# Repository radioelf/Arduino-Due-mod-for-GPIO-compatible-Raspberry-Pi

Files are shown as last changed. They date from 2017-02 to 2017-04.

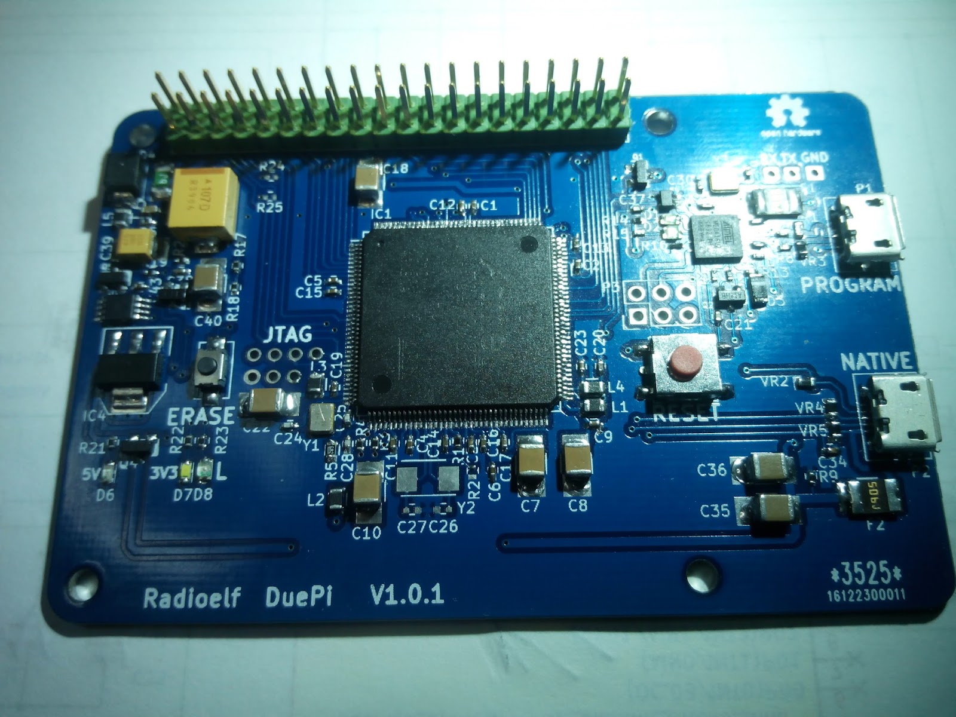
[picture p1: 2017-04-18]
DuePi.jpg

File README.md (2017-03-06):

# Arduino Due mod for GPIO compatible Raspberry Pi
Creative Commons License Disclaimer

UNLESS OTHERWISE MUTUALLY AGREED TO BY THE PARTIES IN WRITING, LICENSOR OFFERS THE WORK AS-IS AND MAKES NO REPRESENTATIONS 
OR WARRANTIES OF ANY KIND CONCERNING THE WORK, EXPRESS, IMPLIED, STATUTORY OR OTHERWISE, INCLUDING, WITHOUT LIMITATION,
WARRANTIES OF TITLE, MERCHANTIBILITY, FITNESS FOR A PARTICULAR PURPOSE, NONINFRINGEMENT, OR THE ABSENCE OF LATENT OR 
OTHER DEFECTS, ACCURACY, OR THE PRESENCE OF ABSENCE OF ERRORS, WHETHER OR NOT DISCOVERABLE. SOME JURISDICTIONS DO NOT 
ALLOW THE EXCLUSION OF IMPLIED WARRANTIES, SO SUCH EXCLUSION MAY NOT APPLY TO YOU. EXCEPT TO THE EXTENT REQUIRED BY 
APPLICABLE LAW, IN NO EVENT WILL LICENSOR BE LIABLE TO YOU ON ANY LEGAL THEORY FOR ANY SPECIAL, INCIDENTAL, CONSEQUENTIAL, 
PUNITIVE OR EXEMPLARY DAMAGES ARISING OUT OF THIS LICENSE OR THE USE OF THE WORK, EVEN IF LICENSOR HAS BEEN ADVISED OF 
THE POSSIBILITY OF SUCH DAMAGES.

http://creativecommons.org/licenses/by-sa/3.0/

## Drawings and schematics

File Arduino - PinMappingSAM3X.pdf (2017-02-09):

# SAM3X-Arduino Pin Mapping

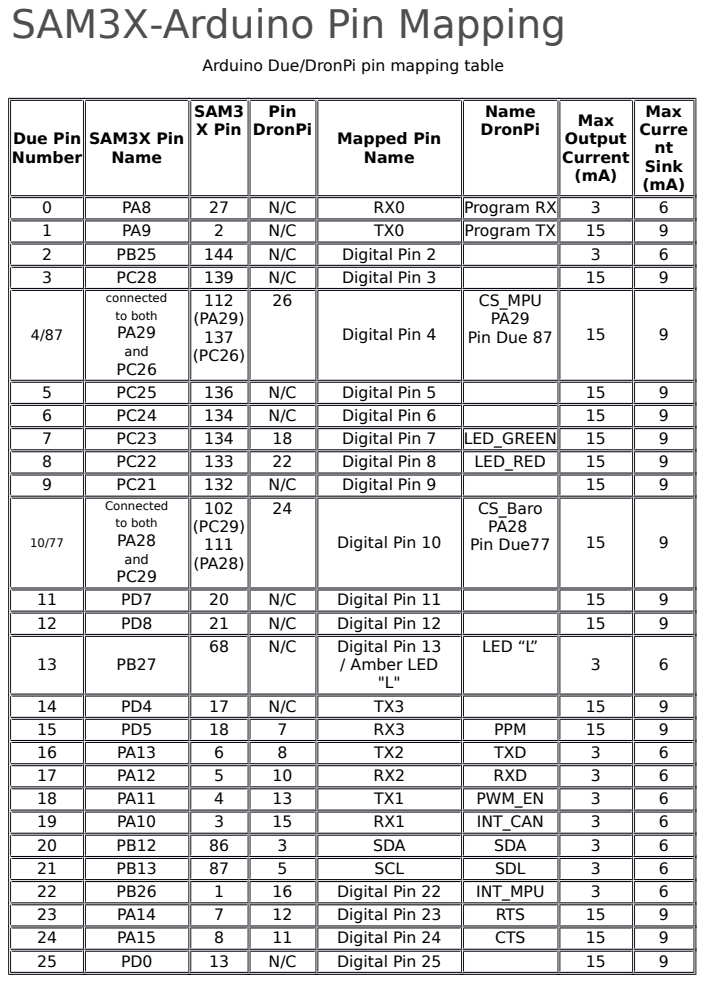
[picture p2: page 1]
Due Pin Number; SAM3X Pin Name; SAM3 X Pin; Pin; DronPi; Mapped Pin; Name; Max; Output Current (mA); Max Curre nt Sink (mA); Program RX; Program TX; Digital Pin 2; Digital Pin 3; connected to both PA29 and PC26; Digital Pin 4; CS_MPU PA29; Pin Due 87; Digital Pin 5; Digital Pin 6; Digital Pin 7; LED_GREEN; Digital Pin 8; LED_RED; Digital Pin 9; Connected to both PA28 and PC29; Digital Pin 10; CS_Baro PA28; Pin Due77; Digital Pin 11; Digital Pin 12; Digital Pin 13; / Amber LED "L"; LED “L”; PPM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

Arduino Due/DronPi pin mapping table

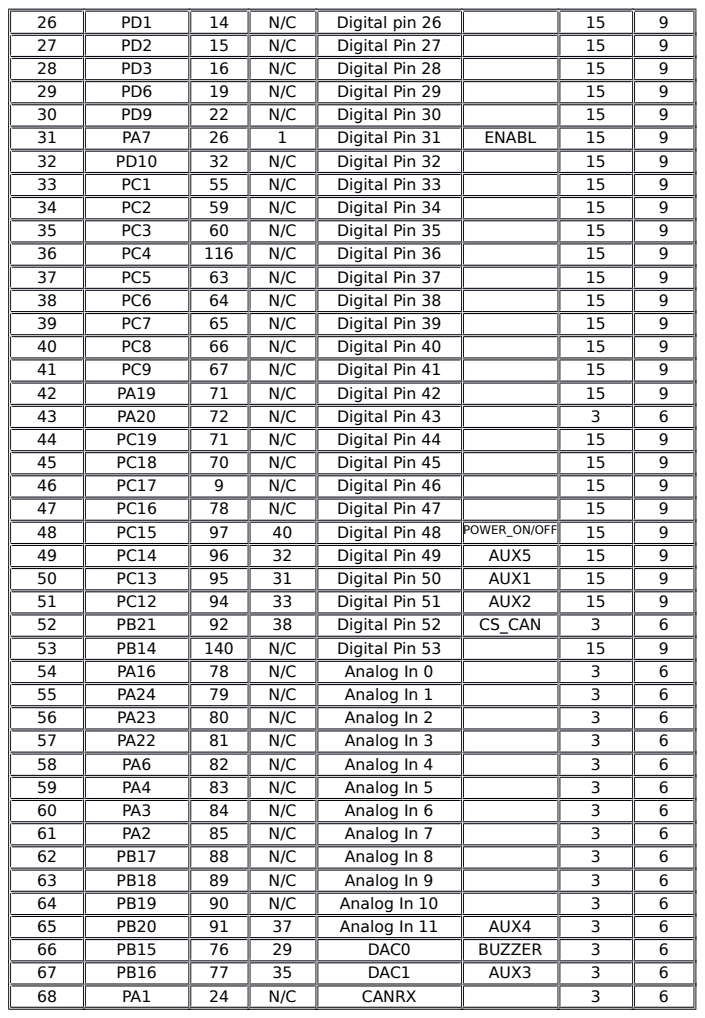
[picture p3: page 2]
Digital pin 26; Digital Pin 27; Digital Pin 28; Digital Pin 29; Digital Pin 30; Digital Pin 31; ENABL; Digital Pin 32; Digital Pin 33; Digital Pin 34; Digital Pin 35; Digital Pin 36; Digital Pin 37; Digital Pin 38; Digital Pin 39; Digital Pin 40; Digital Pin 41; Digital Pin 42; Digital Pin 43; Digital Pin 44; Digital Pin 45; Digital Pin 46; Digital Pin 47; Digital Pin 48 POWER_ON/OFF; Digital Pin 49; AUX5; Digital Pin 50; AUX1; Digital Pin 51; AUX2; Digital Pin 52; CS_CAN; Digital Pin 53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

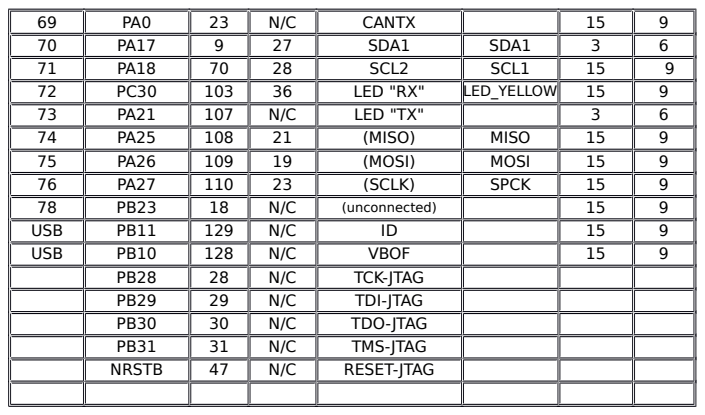
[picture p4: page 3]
CANTX; SDA1; SCL2; SCL1; LED "RX"; LED_YELLOW; LED "TX"; (MISO); MISO; (MOSI); MOSI; (SCLK); SPCK; (unconnected); USB; VBOF; TCK-JTAG; TDI-JTAG; TDO-JTAG; TMS-JTAG; NRSTB; RESET-JTAG

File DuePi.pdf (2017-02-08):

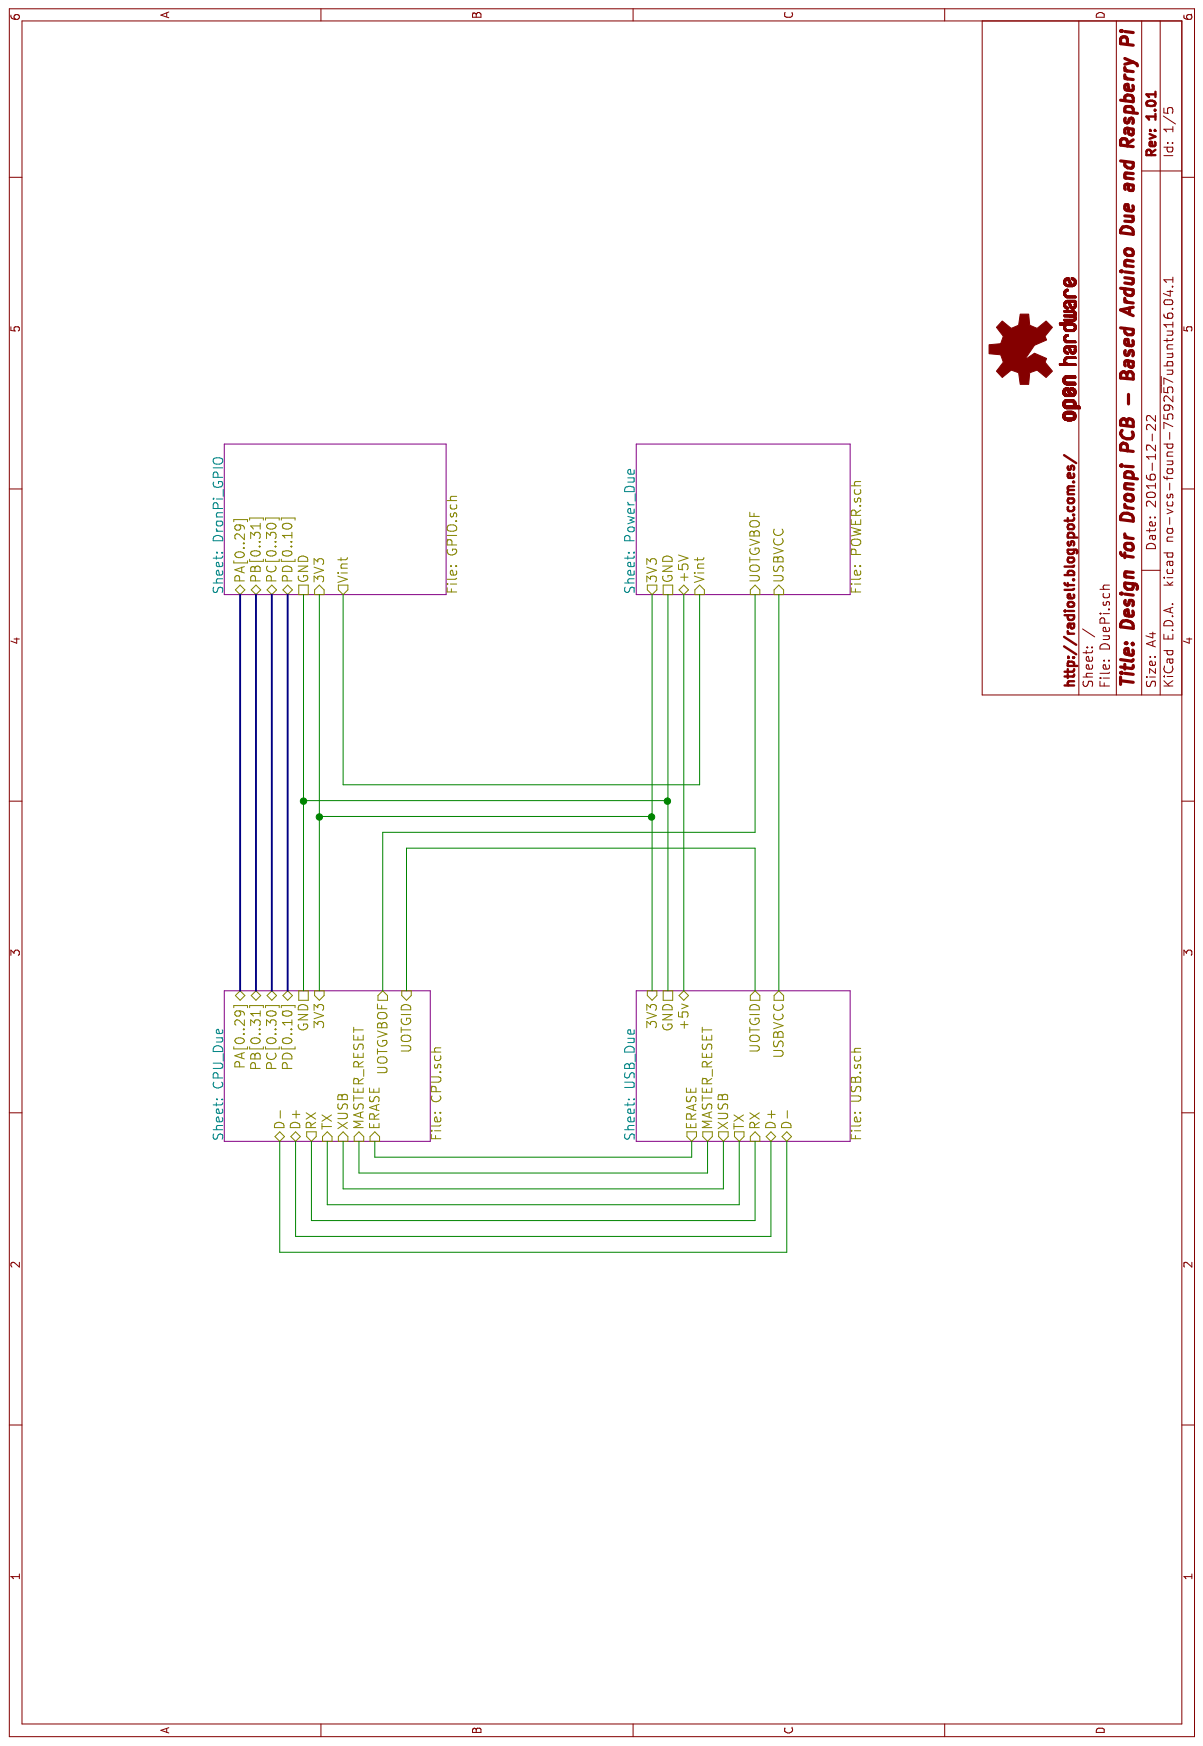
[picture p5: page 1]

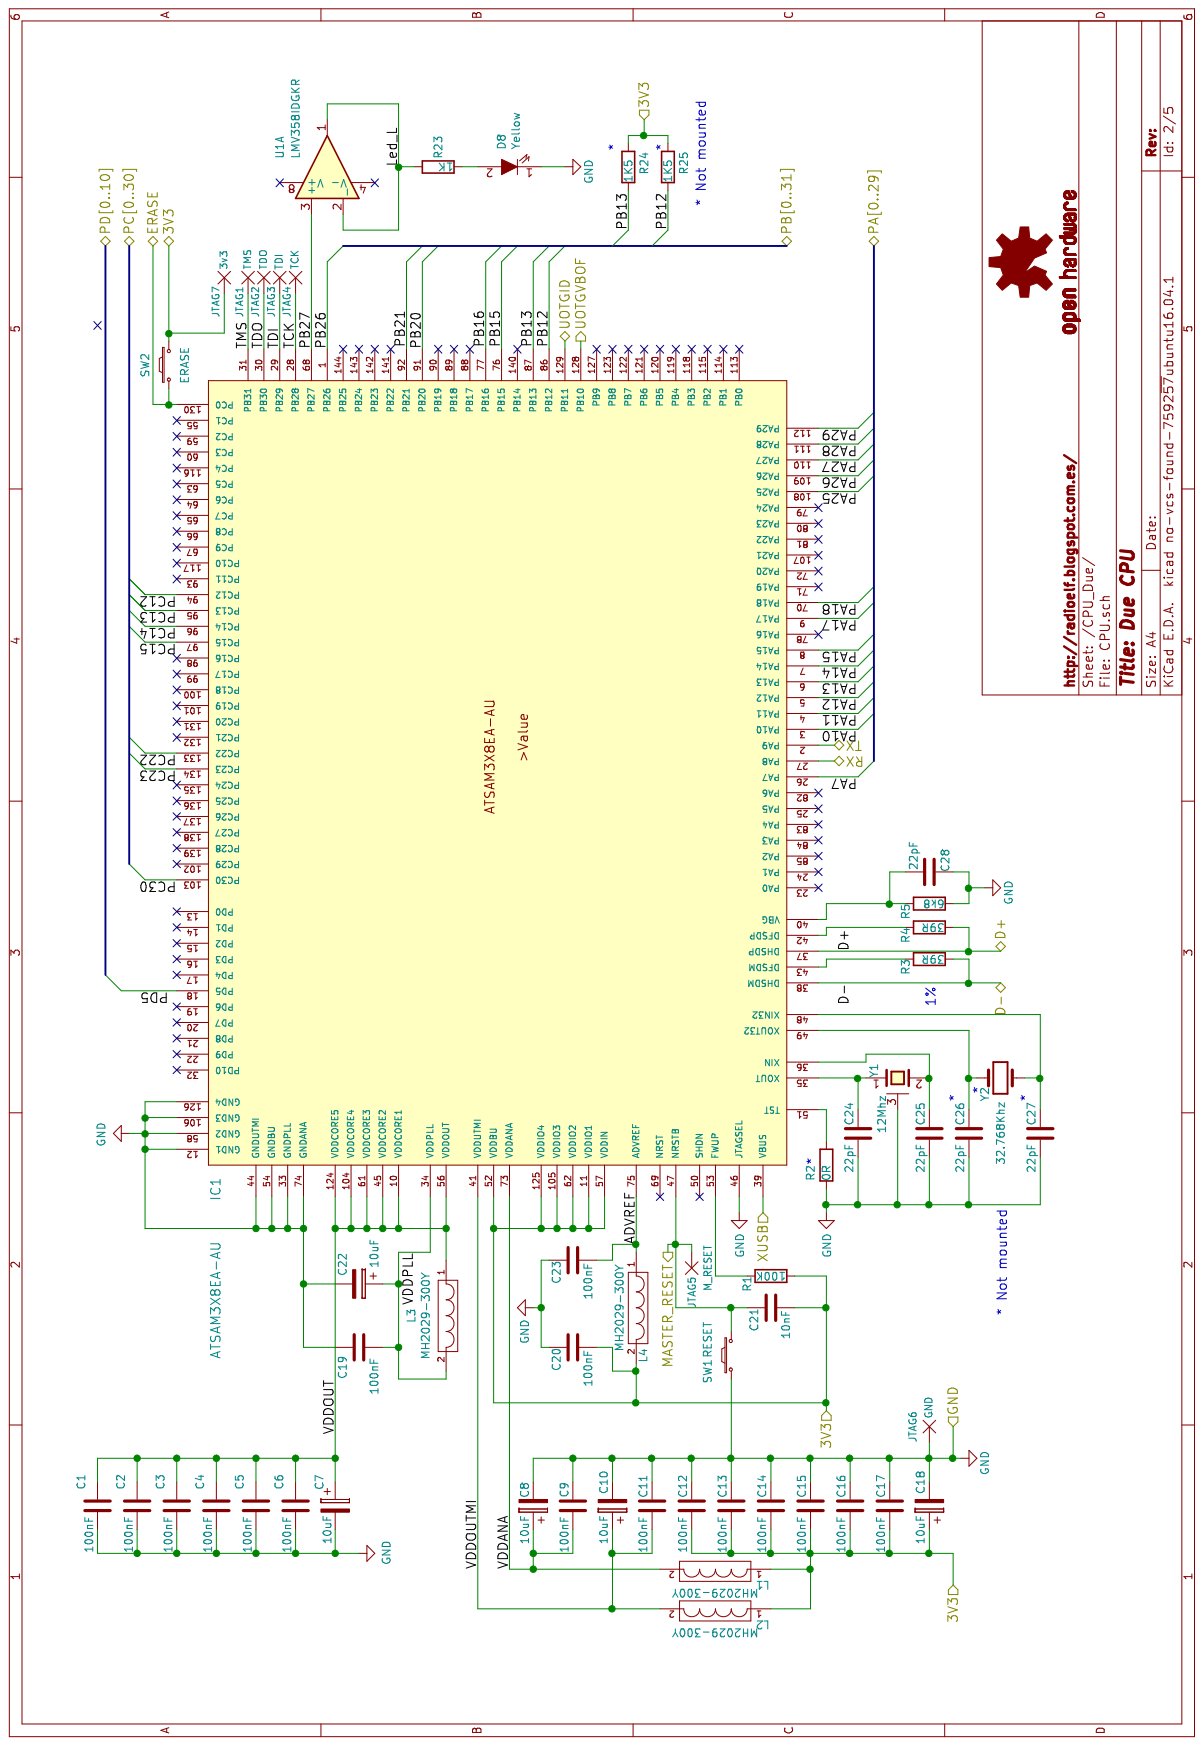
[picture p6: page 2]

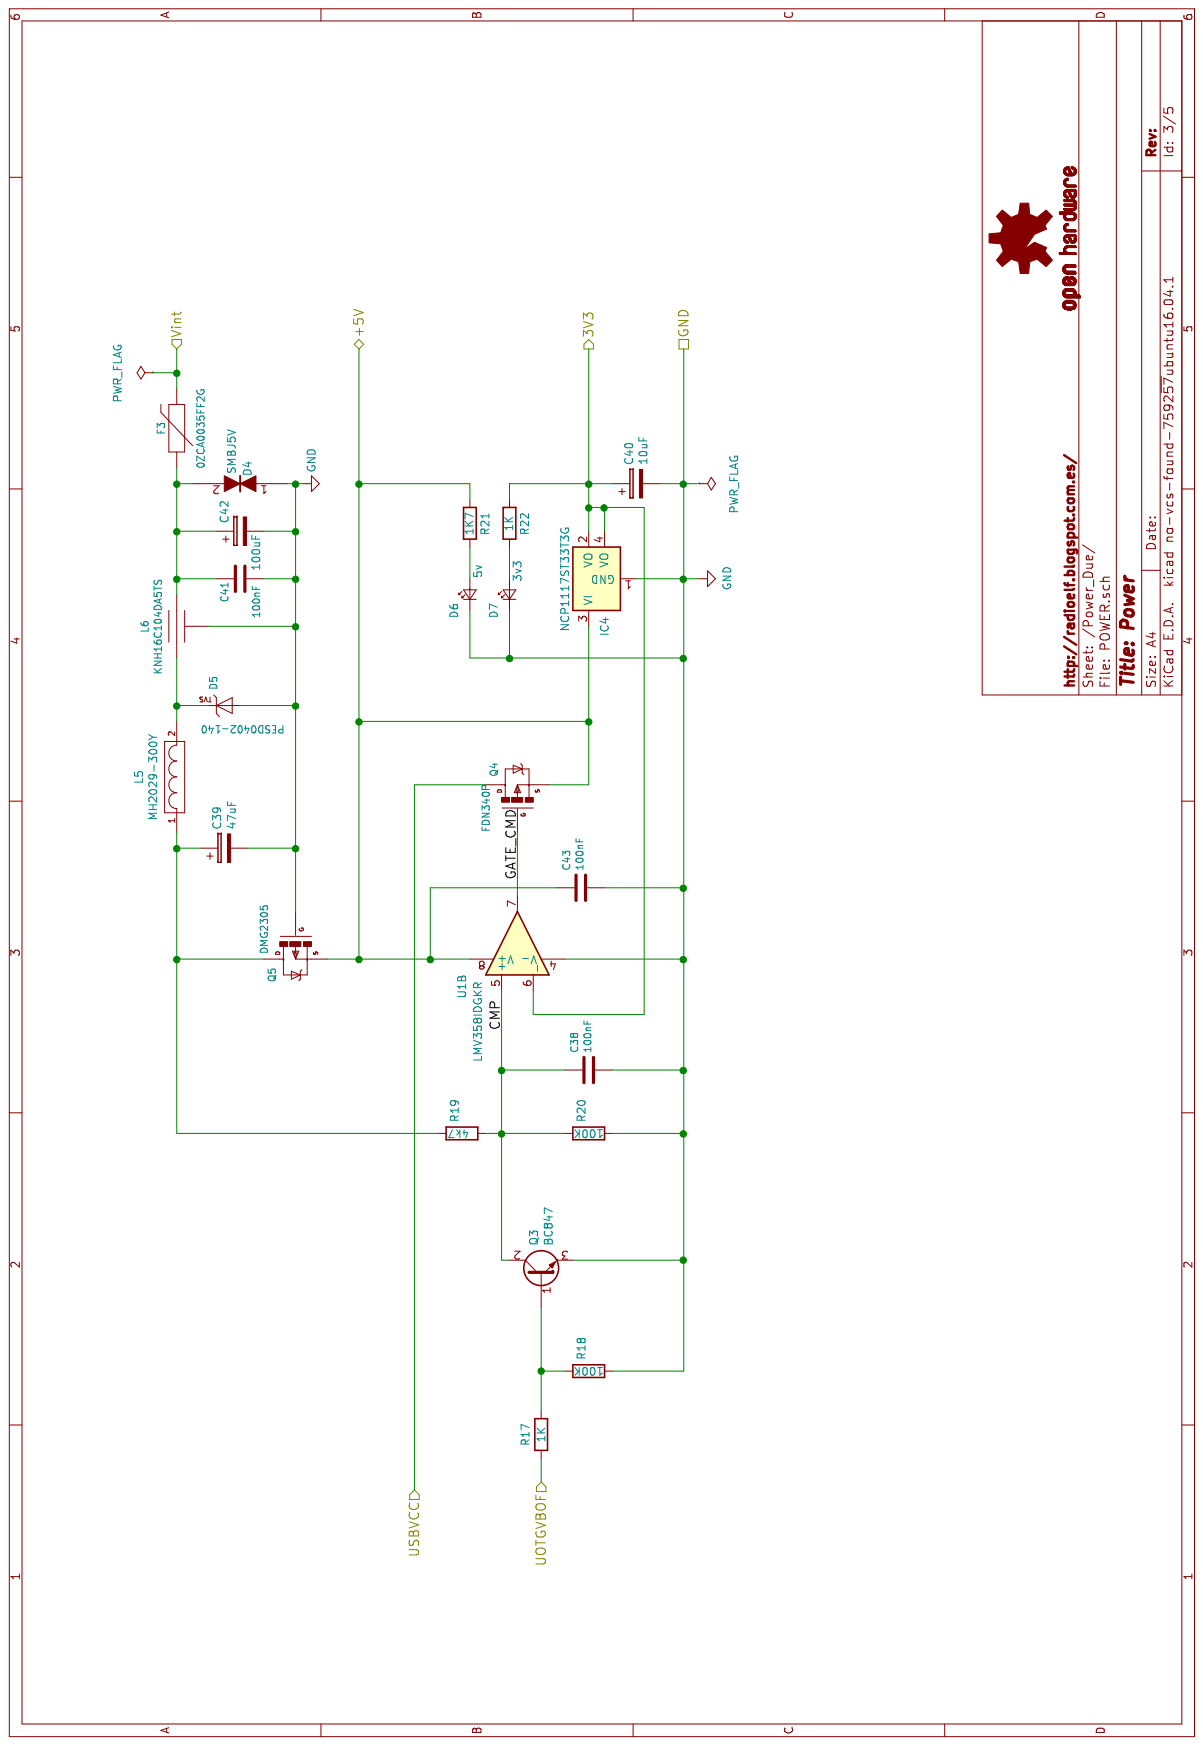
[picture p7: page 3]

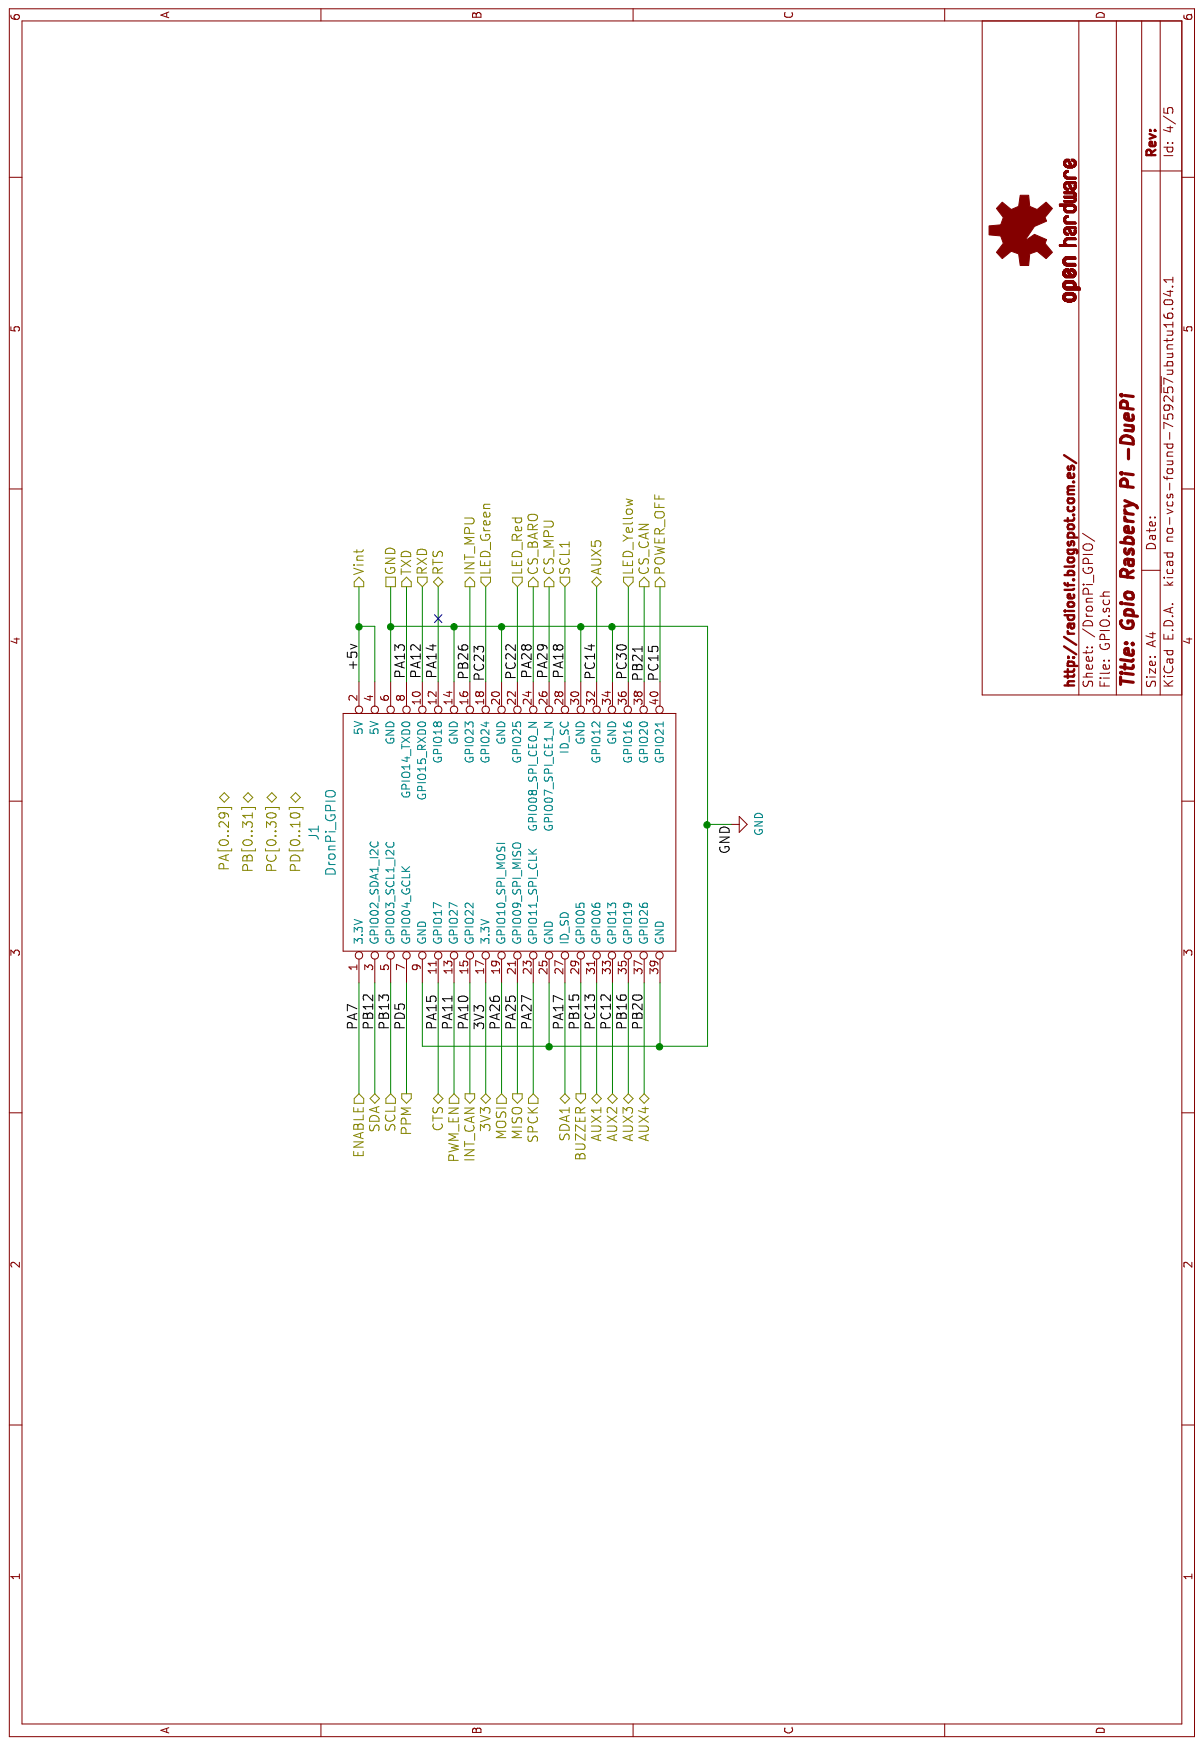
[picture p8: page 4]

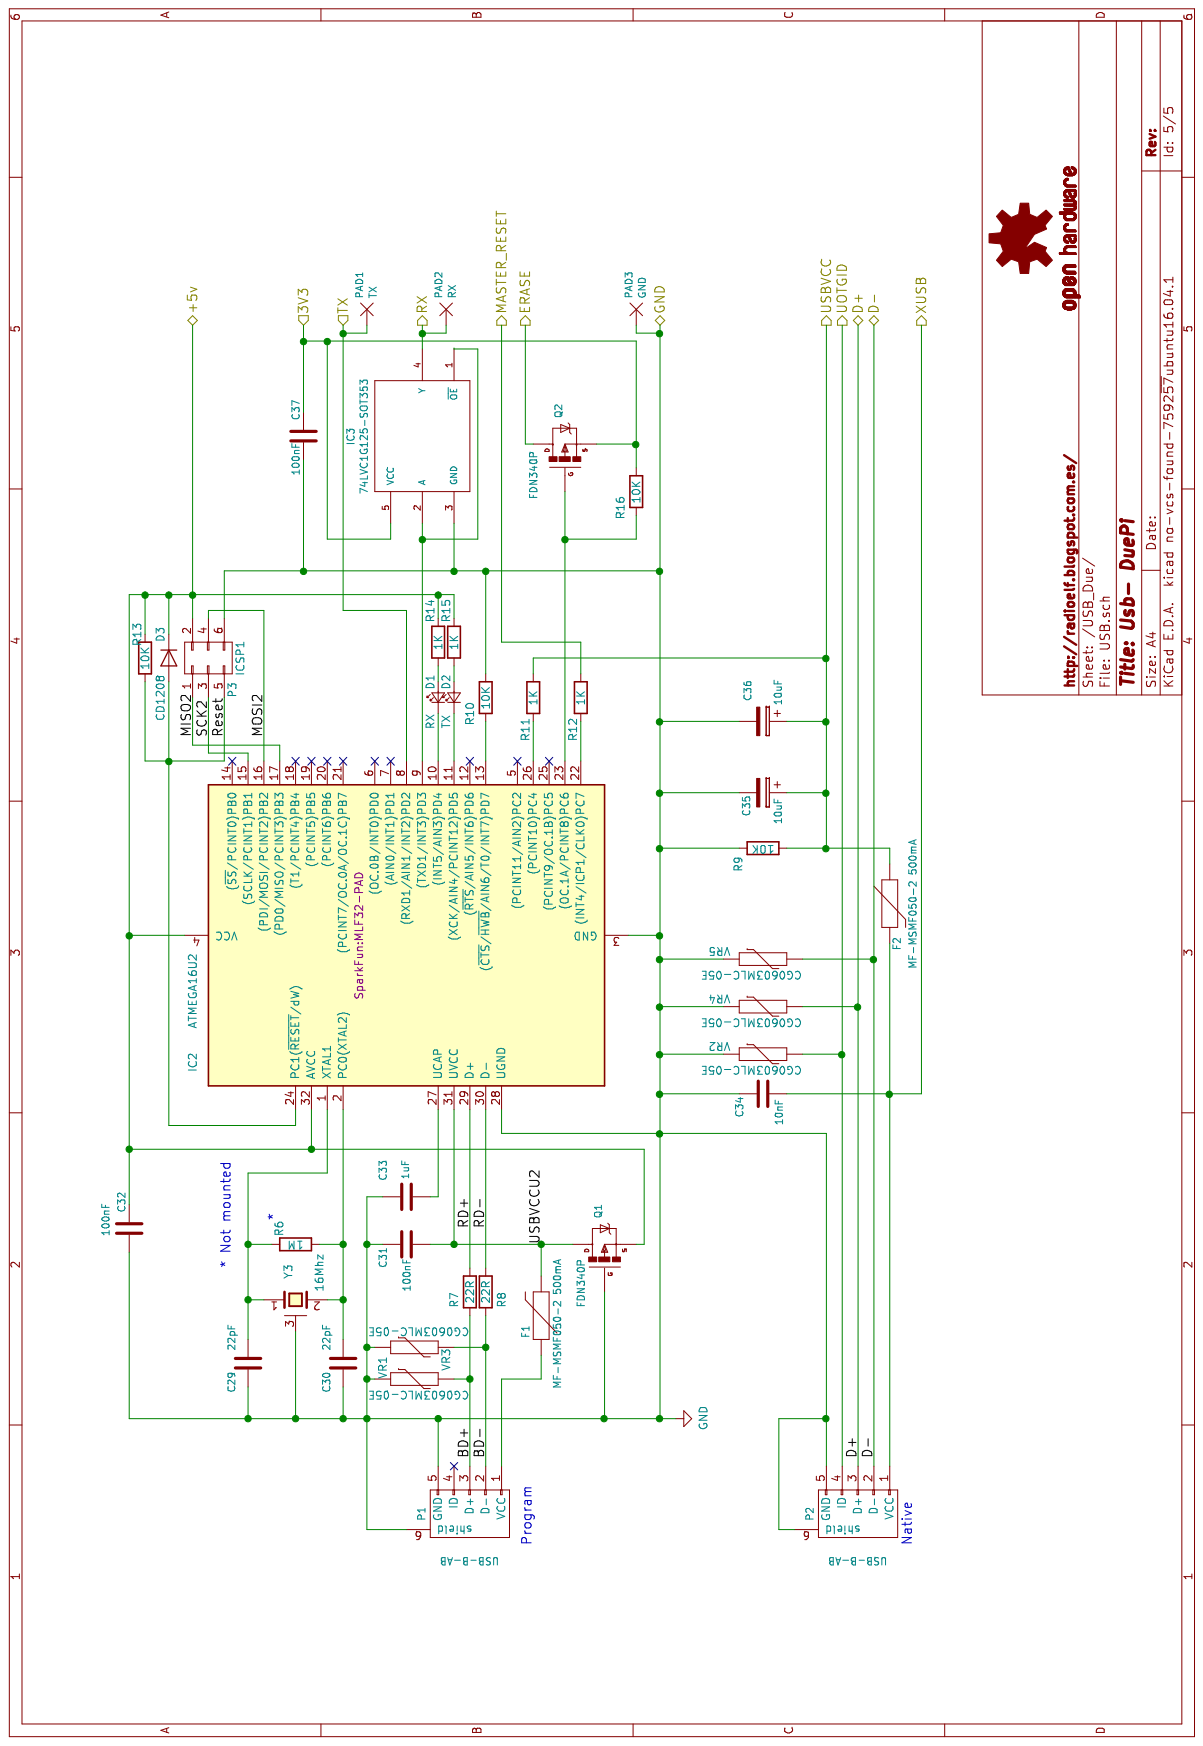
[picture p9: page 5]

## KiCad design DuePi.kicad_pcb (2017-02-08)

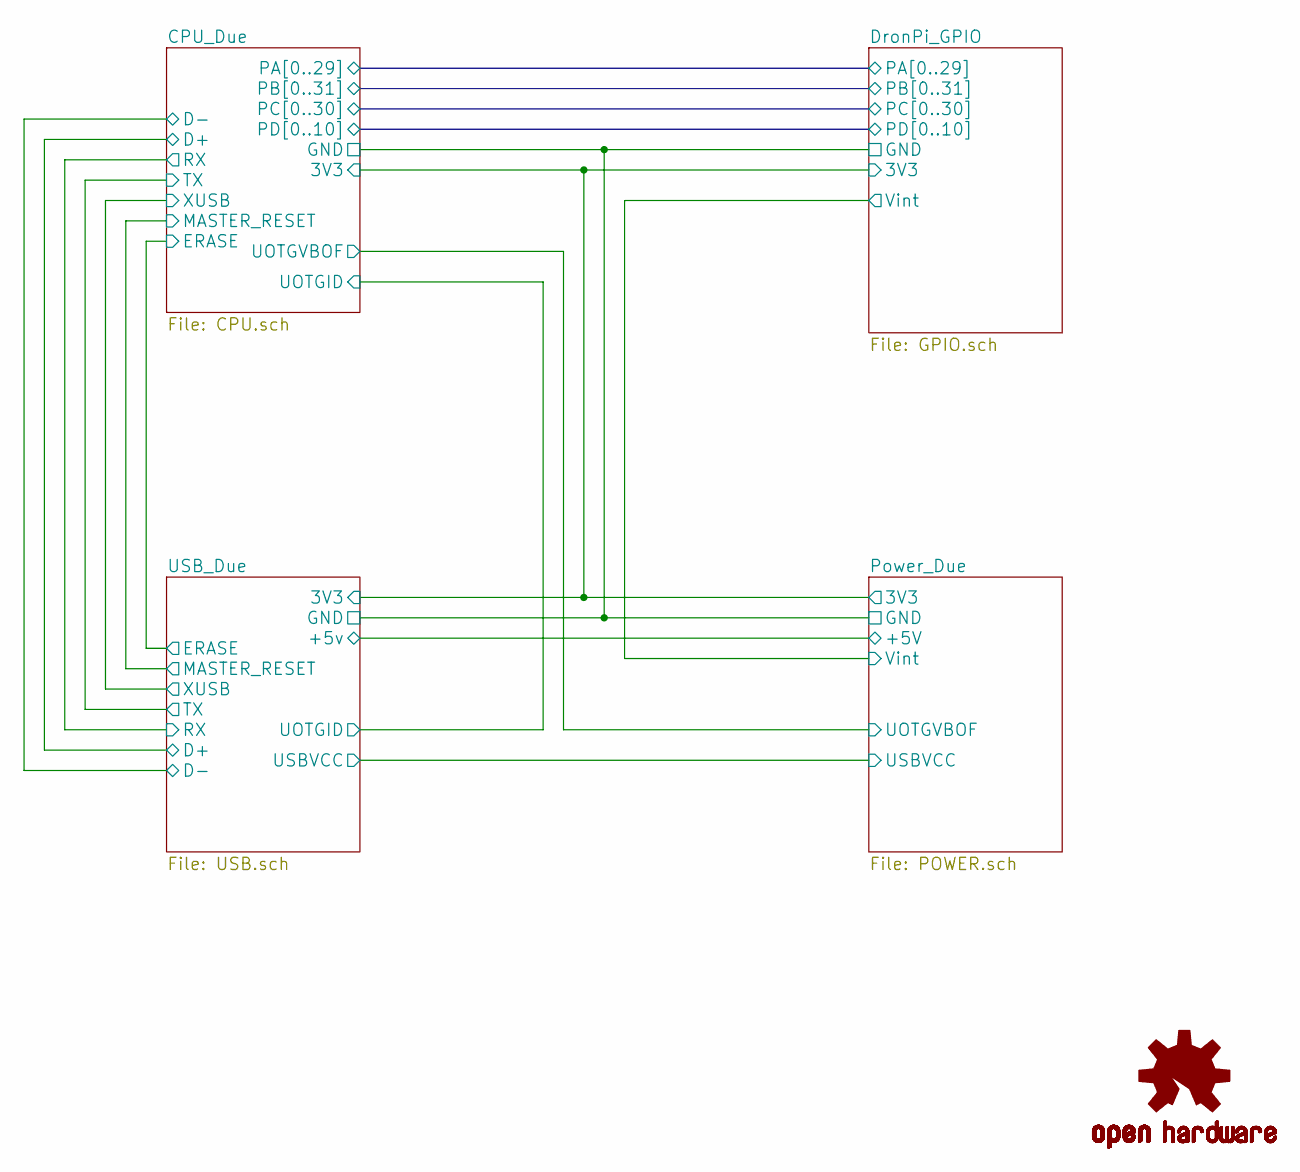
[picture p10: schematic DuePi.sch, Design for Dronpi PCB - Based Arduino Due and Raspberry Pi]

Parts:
M1: OSHW-LOGOL; OSHW-Logo2_7.3x6mm_SilkScreen

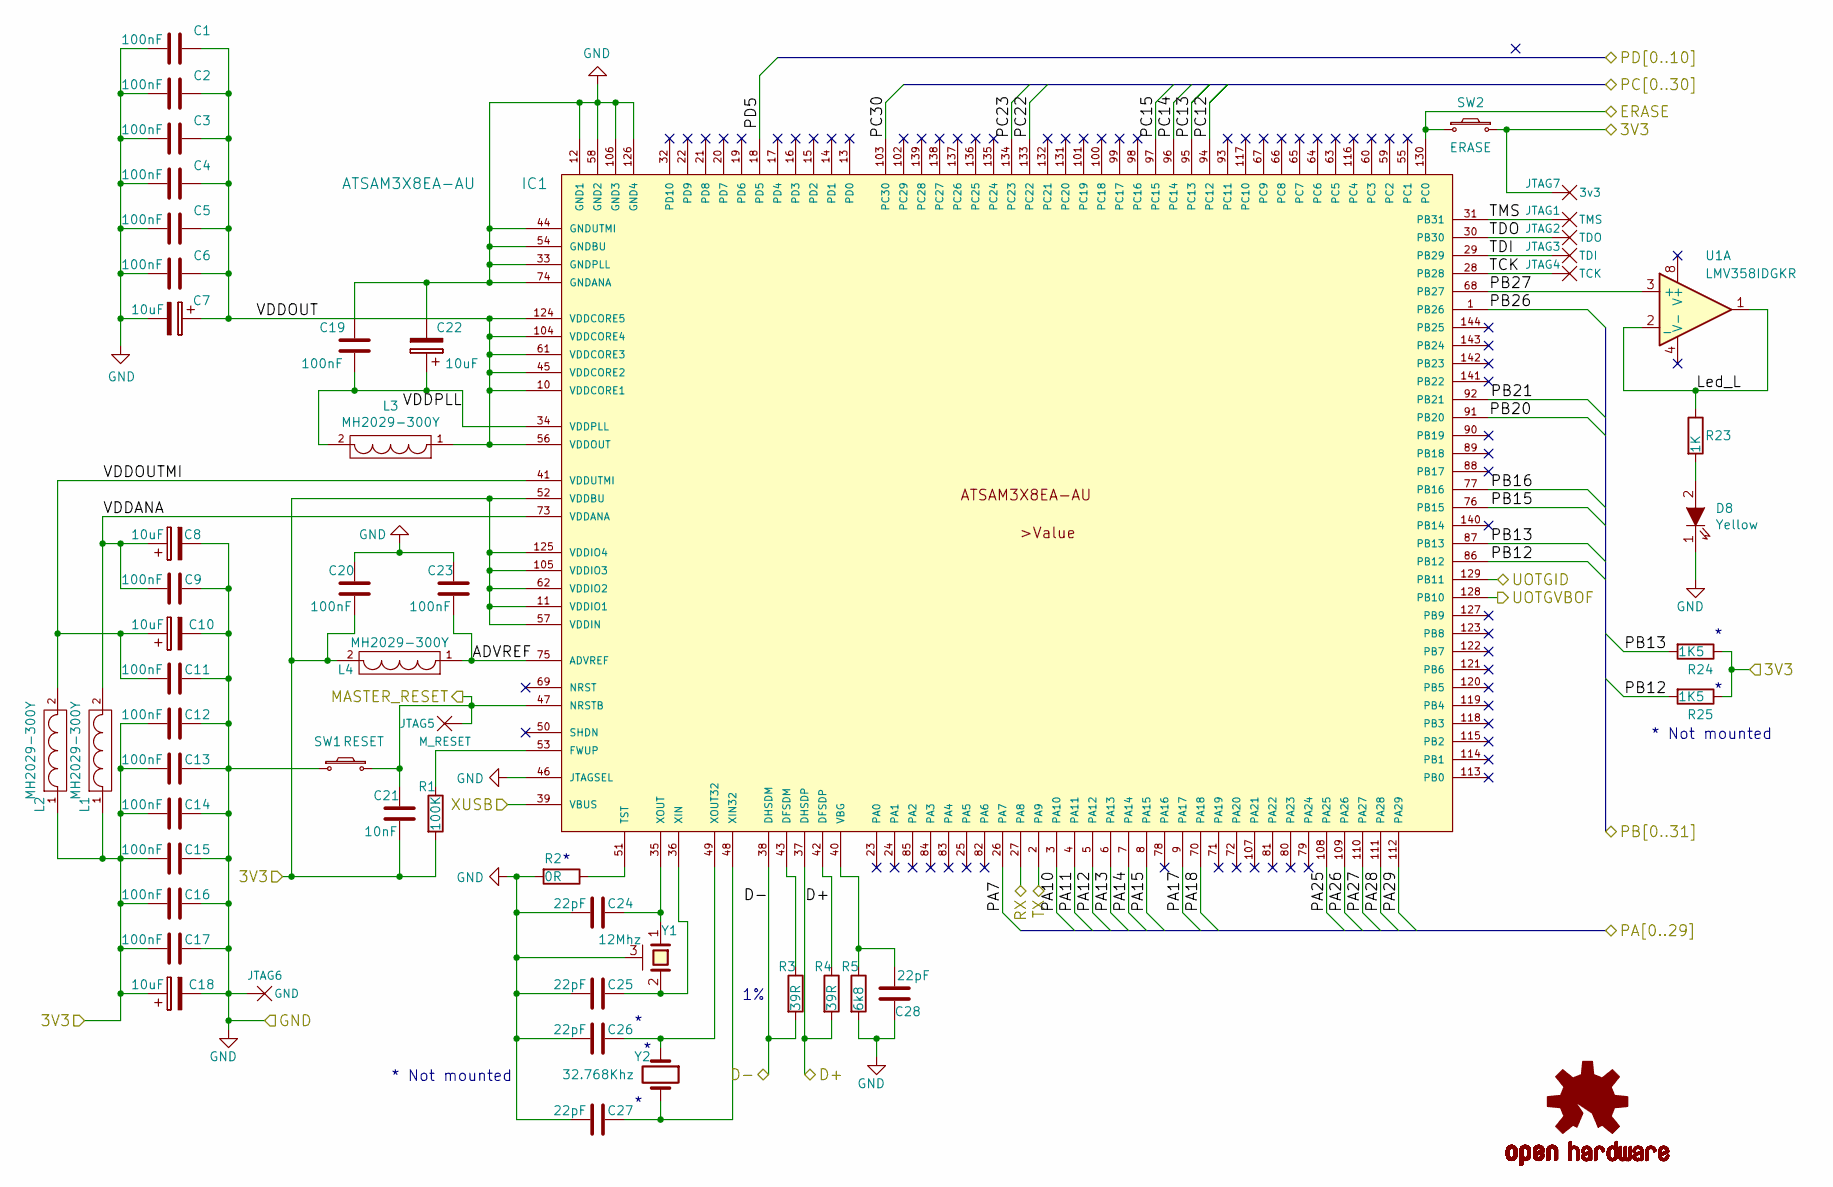
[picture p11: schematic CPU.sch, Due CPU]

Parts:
C1, C2, C3, C4, C5, C6, C9, C11, C12, C13, C14, C15, C16, C17, C19, C20, C23: 100nF; C_0402
C7, C8, C10, C18, C22: 10uF; C_1210_HandSoldering
C21: 10nF; C_0402
C24, C25, C26, C27, C28: 22pF; C_0402
D8: Yellow; LED_0603
IC1: ATSAM3X8EA-AU; LQFP-144_20x20mm_Pitch0.5mm
JTAG1: TMS; Measurement_Point_Round-TH_Small
JTAG2: TDO; Measurement_Point_Round-TH_Small
JTAG3: TDI; Measurement_Point_Round-TH_Small
JTAG4: TCK; Measurement_Point_Round-TH_Small
JTAG5: M_RESET; Measurement_Point_Round-TH_Small
JTAG6: GND; Measurement_Point_Round-TH_Small
JTAG7: 3v3; Measurement_Point_Round-TH_Small
L1, L2, L3, L4: MH2029-300Y; R_0805
M2: OSHW-LOGOL; OSHW-LOGO-L
R1: 100K; R_0402
R2: 0R; R_0402
R3, R4: 39R; R_0402
R5: 6k8; R_0603
R23: 1K; R_0402
R24, R25: 1K5; R_0402
SW1: RESET; SW_SPST_B3S-1000
SW2: ERASE; SW_SPST_EVQPE1
U1: LMV358IDGKR; MSOP8
Y1: 12Mhz; Crystal_SMD_2520_4Pads
Y2: 32.768Khz; Crystal_SMD_5032_2Pads

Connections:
/CPU_Due/3V3: C12.1, C13.1, C14.1, C15.1, C16.1, C17.1, C18.1, C20.1, C21.1, IC1.11 (VDDIO1), IC1.52 (VDDBU), IC1.57 (VDDIN), IC1.62 (VDDIO2), IC1.105 (VDDIO3), IC1.125 (VDDIO4), JTAG7.1, L1.1, L2.1, L4.2, R1.2, R24.1, R25.1, SW2.2; also elsewhere on the board
/CPU_Due/ADVREF: C23.1, IC1.75 (ADVREF), L4.1
/CPU_Due/D+: IC1.37 (DHSDP), R4.2; also elsewhere on the board
/CPU_Due/D-: IC1.38 (DHSDM), R3.2; also elsewhere on the board
/CPU_Due/ERASE: IC1.130 (PC0), SW2.1; also elsewhere on the board
/CPU_Due/Led_L: R23.1, U1.1, U1.2 (_)
/CPU_Due/MASTER_RESET: C21.2, IC1.47 (NRSTB), JTAG5.1, SW1.2; also elsewhere on the board
/CPU_Due/PB27: IC1.68 (PB27), U1.3 (+)
/CPU_Due/RX: IC1.27 (PA8); also elsewhere on the board
/CPU_Due/TCK: IC1.28 (PB28), JTAG4.1
/CPU_Due/TDI: IC1.29 (PB29), JTAG3.1
/CPU_Due/TDO: IC1.30 (PB30), JTAG2.1
/CPU_Due/TMS: IC1.31 (PB31), JTAG1.1
/CPU_Due/TX: IC1.2 (PA9); also elsewhere on the board
/CPU_Due/UOTGID: IC1.129 (PB11); also elsewhere on the board
/CPU_Due/UOTGVBOF: IC1.128 (PB10); also elsewhere on the board
/CPU_Due/VDDANA: C8.1, C9.1, IC1.73 (VDDANA), L1.2
/CPU_Due/VDDOUT: C1.2, C2.2, C3.2, C4.2, C5.2, C6.2, C7.1, IC1.10 (VDDCORE1), IC1.45 (VDDCORE2), IC1.56 (VDDOUT), IC1.61 (VDDCORE3), IC1.104 (VDDCORE4), IC1.124 (VDDCORE5), L3.1
/CPU_Due/VDDOUTMI: C10.1, C11.1, IC1.41 (VDDUTMI), L2.2
/CPU_Due/VDDPLL: C19.1, C22.1, IC1.34 (VDDPLL), L3.2
/CPU_Due/XUSB: IC1.39 (VBUS); also elsewhere on the board
/DronPi_GPIO/AUX1: IC1.95 (PC13); also elsewhere on the board
/DronPi_GPIO/AUX2: IC1.94 (PC12); also elsewhere on the board
/DronPi_GPIO/AUX3: IC1.77 (PB16); also elsewhere on the board
/DronPi_GPIO/AUX4: IC1.91 (PB20); also elsewhere on the board
/DronPi_GPIO/AUX5: IC1.96 (PC14); also elsewhere on the board
/DronPi_GPIO/BUZZER: IC1.76 (PB15); also elsewhere on the board
/DronPi_GPIO/CS_BARO: IC1.111 (PA28); also elsewhere on the board
/DronPi_GPIO/CS_CAN: IC1.92 (PB21); also elsewhere on the board
/DronPi_GPIO/CS_MPU: IC1.112 (PA29); also elsewhere on the board
/DronPi_GPIO/CTS: IC1.8 (PA15); also elsewhere on the board
/DronPi_GPIO/ENABLE: IC1.26 (PA7); also elsewhere on the board
/DronPi_GPIO/INT_CAN: IC1.3 (PA10); also elsewhere on the board
/DronPi_GPIO/INT_MPU: IC1.1 (PB26); also elsewhere on the board
/DronPi_GPIO/LED_Green: IC1.134 (PC23); also elsewhere on the board
/DronPi_GPIO/LED_Red: IC1.133 (PC22); also elsewhere on the board
/DronPi_GPIO/LED_Yellow: IC1.103 (PC30); also elsewhere on the board
/DronPi_GPIO/MISO: IC1.108 (PA25); also elsewhere on the board
/DronPi_GPIO/MOSI: IC1.109 (PA26); also elsewhere on the board
/DronPi_GPIO/POWER_OFF: IC1.97 (PC15); also elsewhere on the board
/DronPi_GPIO/PPM: IC1.18 (PD5); also elsewhere on the board
/DronPi_GPIO/PWM_EN: IC1.4 (PA11); also elsewhere on the board
/DronPi_GPIO/RTS: IC1.7 (PA14); also elsewhere on the board
/DronPi_GPIO/RXD: IC1.5 (PA12); also elsewhere on the board
/DronPi_GPIO/SCL: IC1.87 (PB13), R24.2; also elsewhere on the board
/DronPi_GPIO/SCL1: IC1.70 (PA18); also elsewhere on the board
/DronPi_GPIO/SDA: IC1.86 (PB12), R25.2; also elsewhere on the board
/DronPi_GPIO/SDA1: IC1.9 (PA17); also elsewhere on the board
/DronPi_GPIO/SPCK: IC1.110 (PA27); also elsewhere on the board
/DronPi_GPIO/TXD: IC1.6 (PA13); also elsewhere on the board
/Power_Due/+5V: U1.8 (V+); also elsewhere on the board
GND: C1.1, C2.1, C3.1, C4.1, C5.1, C6.1, C7.2, C8.2, C9.2, C10.2, C11.2, C12.2, C13.2, C14.2, C15.2, C16.2, C17.2, C18.2, C19.2, C20.2, C22.2, C23.2, C24.1, C25.1, C26.1, C27.1, C28.2, D8.1 (K), IC1.12 (GND1), IC1.33 (GNDPLL), IC1.44 (GNDUTMI), IC1.46 (JTAGSEL), IC1.54 (GNDBU), IC1.58 (GND2), IC1.74 (GNDANA), IC1.106 (GND3), IC1.126 (GND4), JTAG6.1, R2.2, R5.2, SW1.1, U1.4 (V-), Y1.3 (case); also elsewhere on the board
unnamed: C24.2, IC1.35 (XOUT), Y1.1
unnamed: C25.2, IC1.36 (XIN), Y1.2
unnamed: C26.2, IC1.49 (XOUT32), Y2.1
unnamed: C27.2, IC1.48 (XIN32), Y2.2
unnamed: C28.1, IC1.40 (VBG), R5.1
unnamed: D8.2 (A), R23.2
unnamed: IC1.42 (DFSDP), R4.1
unnamed: IC1.43 (DFSDM), R3.1
unnamed: IC1.51 (TST), R2.1
unnamed: IC1.53 (FWUP), R1.1

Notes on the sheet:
* Not mounted

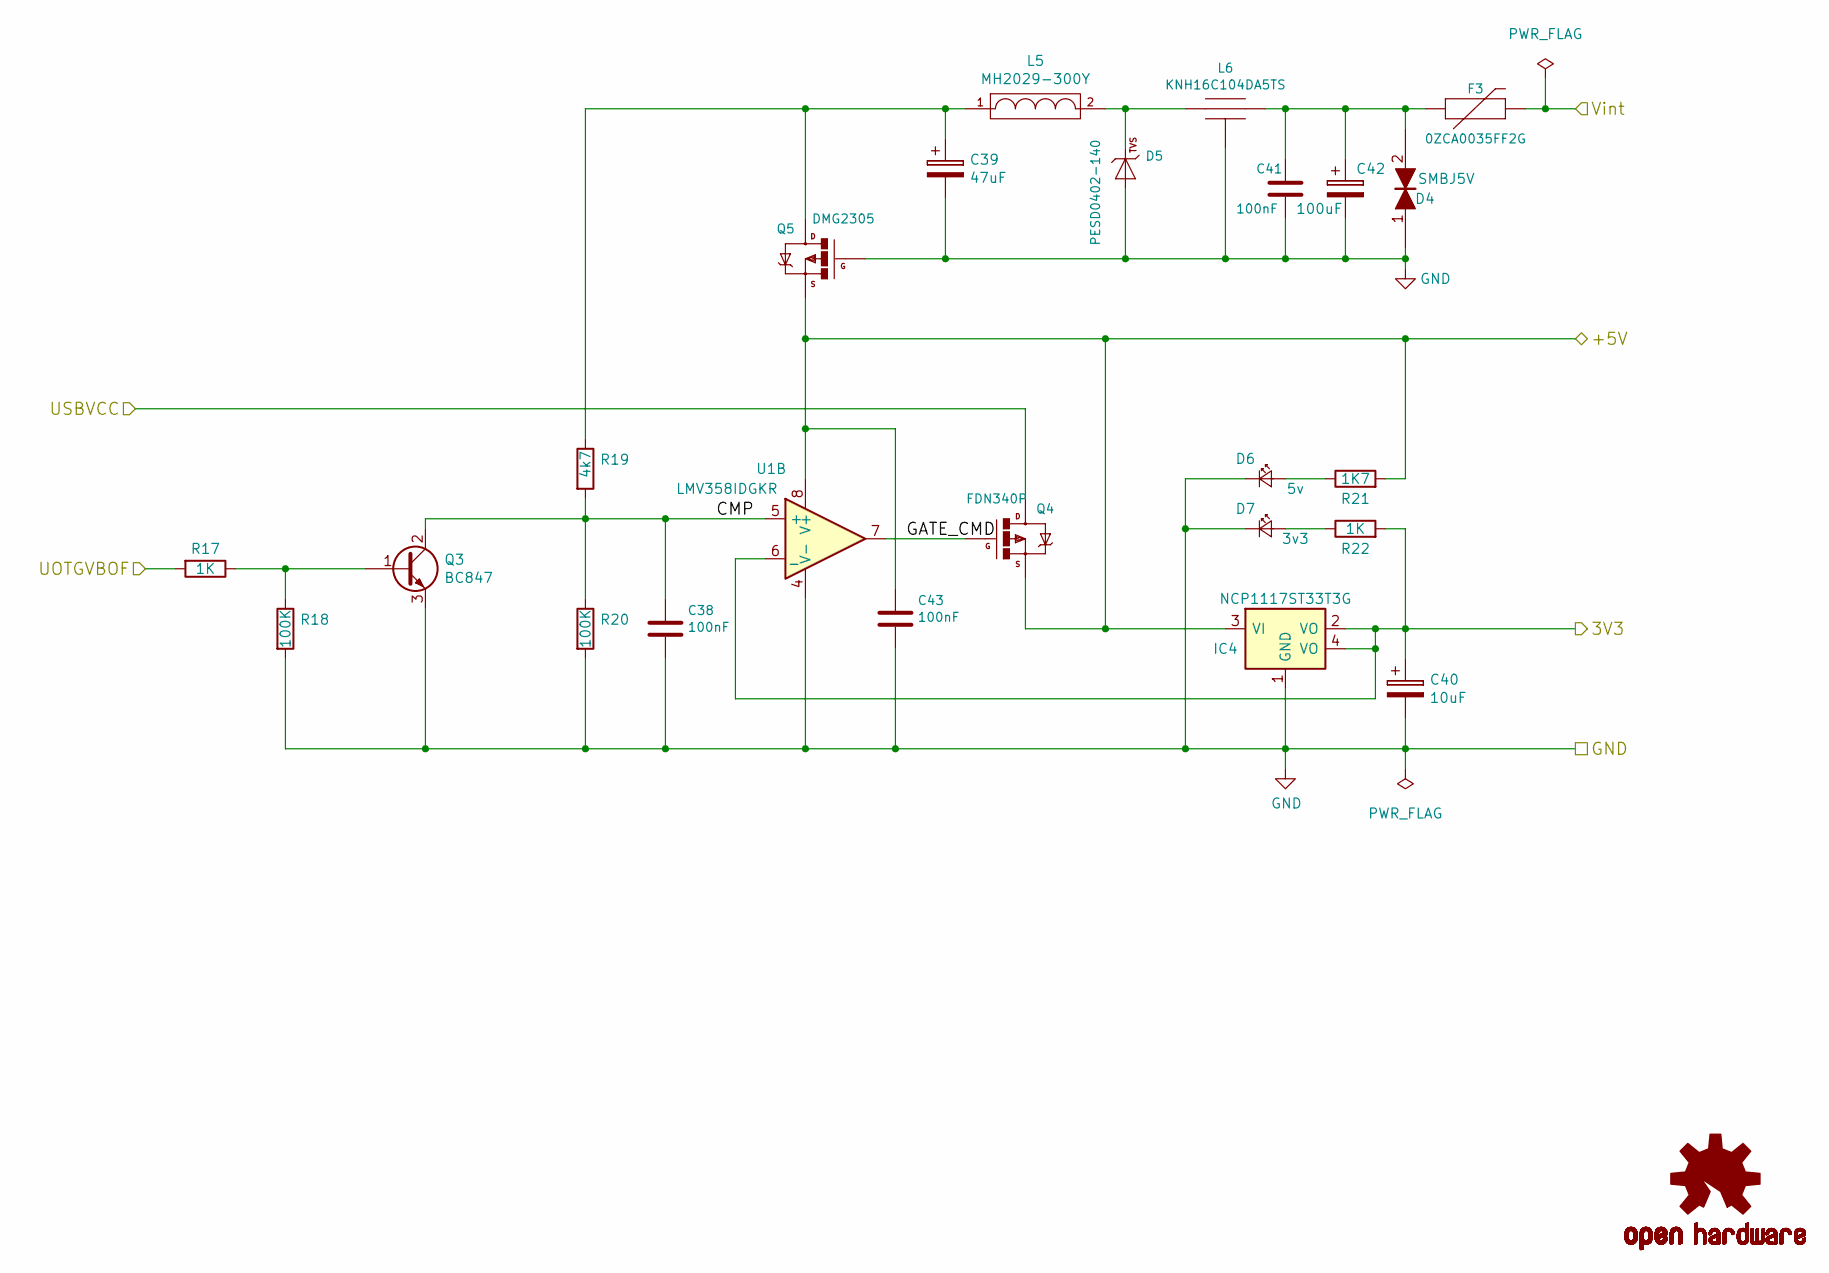
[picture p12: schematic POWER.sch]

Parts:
C38, C41, C43: 100nF; C_0402
C39: 47uF; C_1210_HandSoldering
C40: 10uF; C_1210_HandSoldering
C42: 100uF; TantalC_SizeD_EIA-7343_Reflow
D4: SMBJ5V; DO-214AA
D5: PESD0402-140; C_0402
D6: 5v; LED_0603
D7: 3v3; LED_0603
F3: 0ZCA0035FF2G; Fuse_SMD1206_Wave
IC4: NCP1117ST33T3G; SOT-223
L5: MH2029-300Y; R_0805
L6: KNH16C104DA5TS; KYOCERA-KNH16-DA
M3: OSHW-LOGOL; OSHW-LOGO-L
Q3: BC847; SOT-23
Q4: FDN340P; SOT-23
Q5: DMG2305; SOT-23
R17, R22: 1K; R_0402
R18, R20: 100K; R_0402
R19: 4k7; R_0402
R21: 1K7; R_0402
U1: LMV358IDGKR; MSOP8

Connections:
/CPU_Due/3V3: C40.1, IC4.2 (VO), IC4.4 (VO), R22.2, U1.6 (_); also elsewhere on the board
/CPU_Due/UOTGVBOF: R17.2; also elsewhere on the board
/DronPi_GPIO/Vint: F3.2; also elsewhere on the board
/Power_Due/+5V: C43.1, IC4.3 (VI), Q4.2 (S), Q5.2 (S), R21.2, U1.8 (V+); also elsewhere on the board
/Power_Due/CMP: C38.1, Q3.2 (C), R19.2, R20.1, U1.5 (+)
/Power_Due/GATE_CMD: Q4.1 (G), U1.7
/Power_Due/USBVCC: Q4.3 (D); also elsewhere on the board
GND: C38.2, C39.2, C40.2, C41.2, C42.2, C43.2, D4.1, D5.2 (A), D6.1 (K), D7.1 (K), IC4.1 (GND), L6.P$3, L6.P$4, L6.P$5, Q3.3 (E), Q5.1 (G), R18.2, R20.2, U1.4 (V-); also elsewhere on the board
unnamed: C39.1, L5.1, Q5.3 (D), R19.1
unnamed: C41.1, C42.1, D4.2, F3.1, L6.P$2
unnamed: D5.1 (C), L5.2, L6.P$1
unnamed: D6.2 (A), R21.1
unnamed: D7.2 (A), R22.1
unnamed: Q3.1 (B), R17.1, R18.1

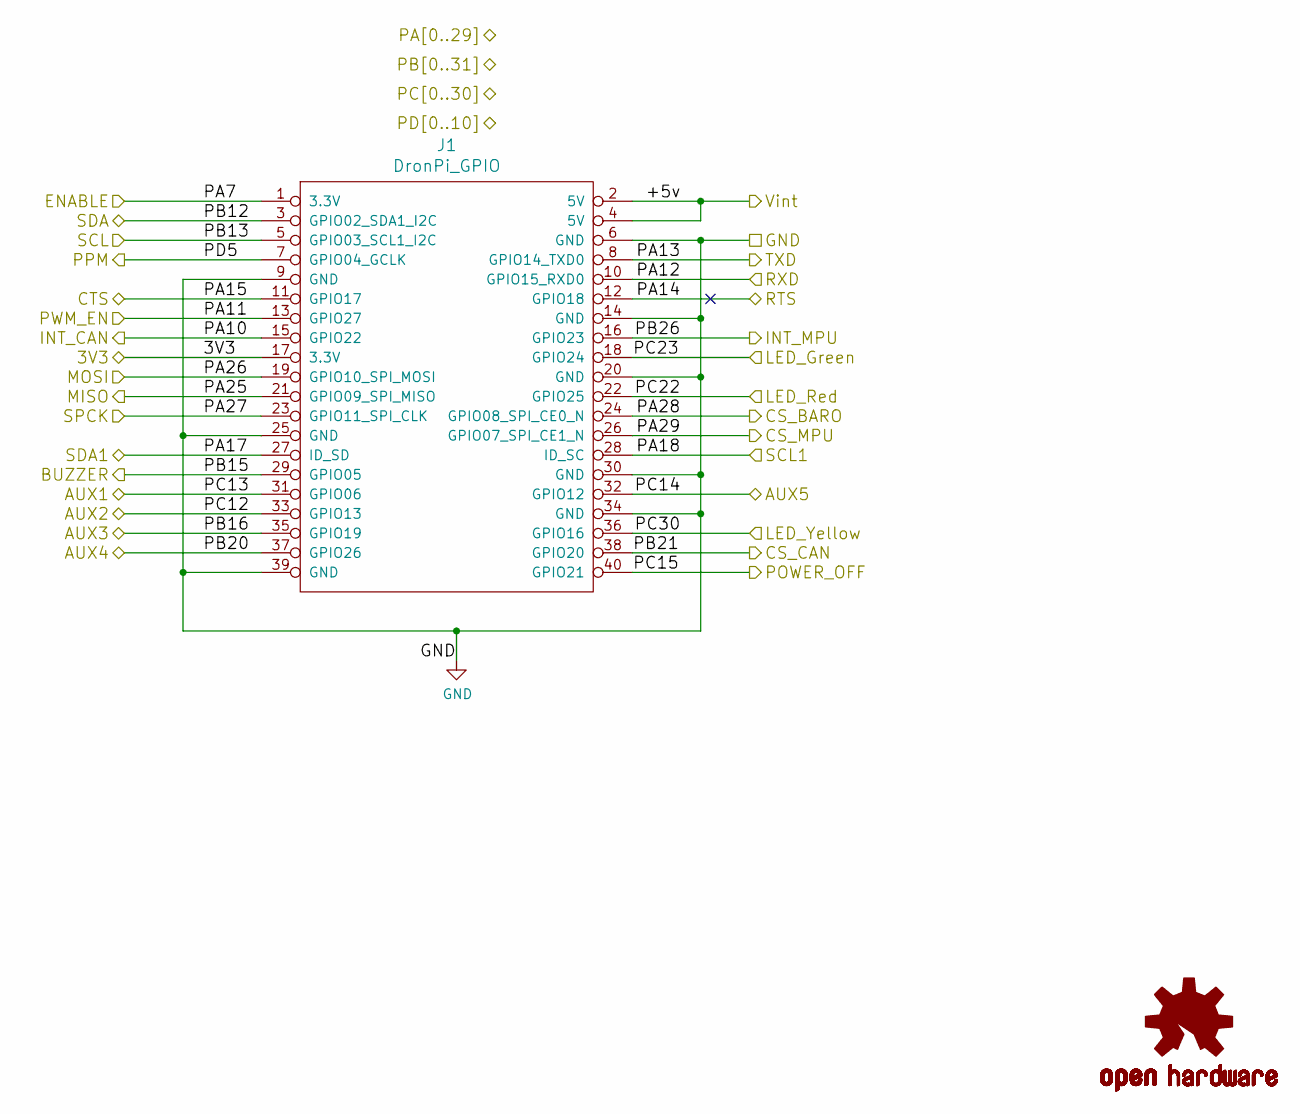
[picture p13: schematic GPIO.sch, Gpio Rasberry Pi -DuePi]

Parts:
J1: DronPi_GPIO; raspberrypi2
M4: OSHW-LOGOL; OSHW-LOGO-L

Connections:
/CPU_Due/3V3: J1.17 (3.3V); also elsewhere on the board
/DronPi_GPIO/AUX1: J1.31 (GPIO06); also elsewhere on the board
/DronPi_GPIO/AUX2: J1.33 (GPIO13); also elsewhere on the board
/DronPi_GPIO/AUX3: J1.35 (GPIO19); also elsewhere on the board
/DronPi_GPIO/AUX4: J1.37 (GPIO26); also elsewhere on the board
/DronPi_GPIO/AUX5: J1.32 (GPIO12); also elsewhere on the board
/DronPi_GPIO/BUZZER: J1.29 (GPIO05); also elsewhere on the board
/DronPi_GPIO/CS_BARO: J1.24 (GPIO08_SPI_CE0_N); also elsewhere on the board
/DronPi_GPIO/CS_CAN: J1.38 (GPIO20); also elsewhere on the board
/DronPi_GPIO/CS_MPU: J1.26 (GPIO07_SPI_CE1_N); also elsewhere on the board
/DronPi_GPIO/CTS: J1.11 (GPIO17); also elsewhere on the board
/DronPi_GPIO/ENABLE: J1.1 (3.3V); also elsewhere on the board
/DronPi_GPIO/INT_CAN: J1.15 (GPIO22); also elsewhere on the board
/DronPi_GPIO/INT_MPU: J1.16 (GPIO23); also elsewhere on the board
/DronPi_GPIO/LED_Green: J1.18 (GPIO24); also elsewhere on the board
/DronPi_GPIO/LED_Red: J1.22 (GPIO25); also elsewhere on the board
/DronPi_GPIO/LED_Yellow: J1.36 (GPIO16); also elsewhere on the board
/DronPi_GPIO/MISO: J1.21 (GPIO09_SPI_MISO); also elsewhere on the board
/DronPi_GPIO/MOSI: J1.19 (GPIO10_SPI_MOSI); also elsewhere on the board
/DronPi_GPIO/POWER_OFF: J1.40 (GPIO21); also elsewhere on the board
/DronPi_GPIO/PPM: J1.7 (GPIO04_GCLK); also elsewhere on the board
/DronPi_GPIO/PWM_EN: J1.13 (GPIO27); also elsewhere on the board
/DronPi_GPIO/RTS: J1.12 (GPIO18); also elsewhere on the board
/DronPi_GPIO/RXD: J1.10 (GPIO15_RXD0); also elsewhere on the board
/DronPi_GPIO/SCL: J1.5 (GPIO03_SCL1_I2C); also elsewhere on the board
/DronPi_GPIO/SCL1: J1.28 (ID_SC); also elsewhere on the board
/DronPi_GPIO/SDA: J1.3 (GPIO02_SDA1_I2C); also elsewhere on the board
/DronPi_GPIO/SDA1: J1.27 (ID_SD); also elsewhere on the board
/DronPi_GPIO/SPCK: J1.23 (GPIO11_SPI_CLK); also elsewhere on the board
/DronPi_GPIO/TXD: J1.8 (GPIO14_TXD0); also elsewhere on the board
/DronPi_GPIO/Vint: J1.2 (5V), J1.4 (5V); also elsewhere on the board
GND: J1.6 (GND), J1.9 (GND), J1.14 (GND), J1.20 (GND), J1.25 (GND), J1.30 (GND), J1.34 (GND), J1.39 (GND); also elsewhere on the board

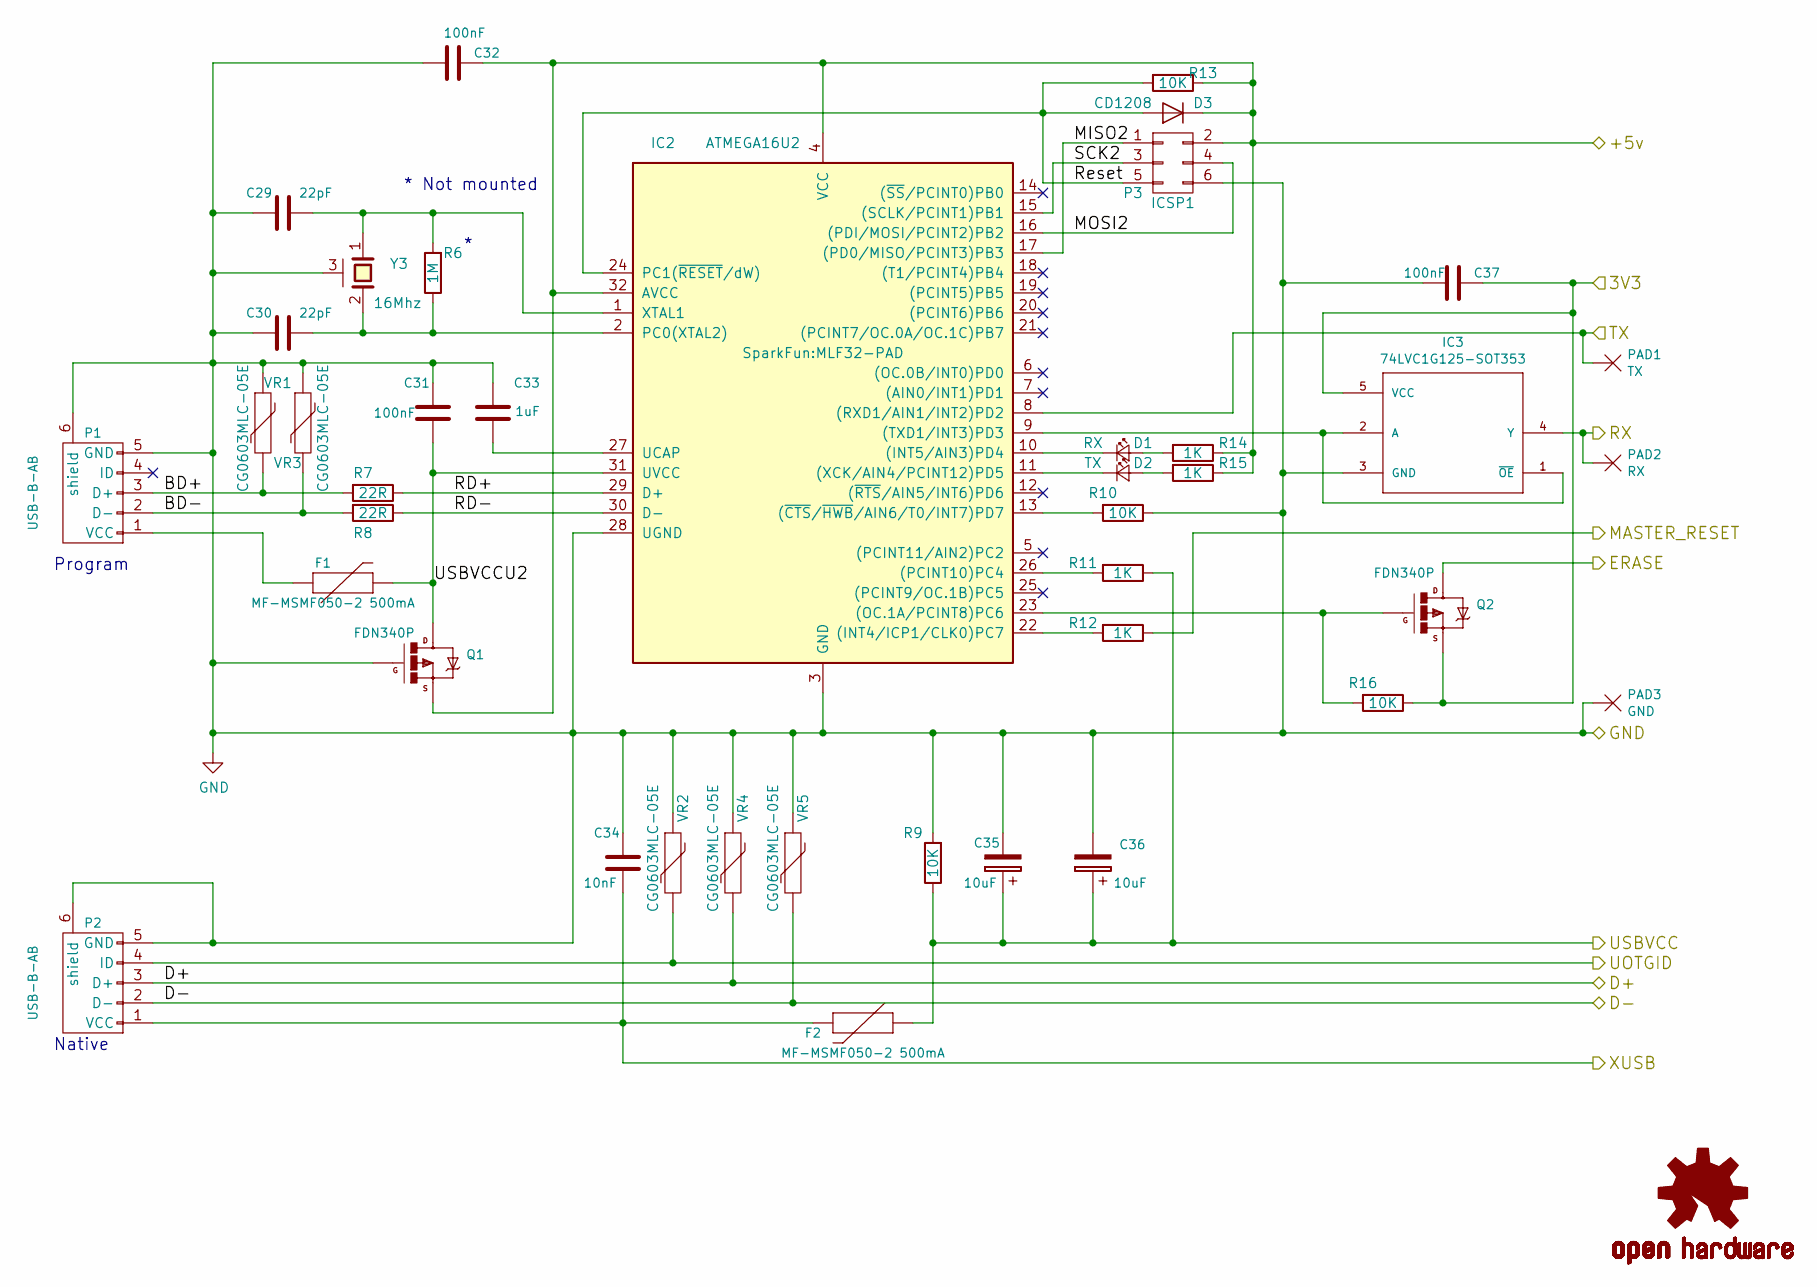
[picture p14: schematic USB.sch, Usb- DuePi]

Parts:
C29, C30: 22pF; C_0402
C31, C32, C37: 100nF; C_0402
C33: 1uF; C_0402
C34: 10nF; C_0402
C35, C36: 10uF; C_1210_HandSoldering
D1: RX; LED_0603
D2: TX; LED_0603
D3: CD1208; D_1206
F1, F2: MF-MSMF050-2 500mA; Neosid_Inductor_SM-NE45_SMD1812
IC2: ATMEGA16U2; MLF32-PAD
IC3: 74LVC1G125-SOT353; SC70-5
M5: OSHW-LOGOL; OSHW-LOGO-L
P1, P2: USB-B-AB; USB_Micro-B
P3: ICSP1; Pin_Header_Straight_2x03
PAD1: TX; Measurement_Point_Square-TH_Small
PAD2: RX; Measurement_Point_Square-TH_Small
PAD3: GND; Measurement_Point_Square-TH_Small
Q1, Q2: FDN340P; SOT-23
R6: 1M; R_0402
R7, R8: 22R; R_0402
R9, R10, R13, R16: 10K; R_0402
R11, R12, R14, R15: 1K; R_0402
VR1, VR2, VR3, VR4, VR5: CG0603MLC-05E; Neosid_Inductor_SM0603CG
Y3: 16Mhz; Crystal_SMD_2520_4Pads

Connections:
/CPU_Due/3V3: C37.1, IC3.5 (VCC), Q2.2 (S), R16.1; also elsewhere on the board
/CPU_Due/D+: P2.3 (D+), VR4.2; also elsewhere on the board
/CPU_Due/D-: P2.2 (D-), VR5.2; also elsewhere on the board
/CPU_Due/ERASE: Q2.3 (D); also elsewhere on the board
/CPU_Due/MASTER_RESET: R12.1; also elsewhere on the board
/CPU_Due/RX: IC3.4 (Y), PAD2.1; also elsewhere on the board
/CPU_Due/TX: IC2.8 ((RXD1/AIN1/INT2)PD2), PAD1.1; also elsewhere on the board
/CPU_Due/UOTGID: P2.4 (ID), VR2.2; also elsewhere on the board
/CPU_Due/XUSB: C34.2, F2.2, P2.1 (VCC); also elsewhere on the board
/Power_Due/+5V: C32.1, D3.1 (K), IC2.4 (VCC), IC2.32 (AVCC), P3.2, Q1.2 (S), R13.1, R14.1, R15.1; also elsewhere on the board
/Power_Due/USBVCC: C35.1, C36.1, F2.1, R9.1, R11.1; also elsewhere on the board
/USB_Due/BD+: P1.3 (D+), R7.2, VR1.2
/USB_Due/BD-: P1.2 (D-), R8.2, VR3.2
/USB_Due/MISO2: IC2.17 ((PD0/MISO/PCINT3)PB3), P3.1
/USB_Due/MOSI2: IC2.16 ((PDI/MOSI/PCINT2)PB2), P3.4
/USB_Due/RD+: IC2.29 (D+), R7.1
/USB_Due/RD-: IC2.30 (D-), R8.1
/USB_Due/Reset: D3.2 (A), IC2.24 (PC1(~RESET~/dW)), P3.5, R13.2
/USB_Due/SCK2: IC2.15 ((SCLK/PCINT1)PB1), P3.3
/USB_Due/USBVCCU2: C31.2, F1.2, IC2.31 (UVCC), Q1.3 (D)
GND: C29.1, C30.1, C31.1, C32.2, C33.1, C34.1, C35.2, C36.2, C37.2, IC2.3 (GND), IC2.28 (UGND), IC3.3 (GND), P1.5 (GND), P1.6 (shield), P2.5 (GND), P2.6 (shield), P3.6, PAD3.1, Q1.1 (G), R9.2, R10.1, VR1.1, VR2.1, VR3.1, VR4.1, VR5.1, Y3.3 (case); also elsewhere on the board
unnamed: C29.2, IC2.1 (XTAL1), R6.2, Y3.1
unnamed: C30.2, IC2.2 (PC0(XTAL2)), R6.1, Y3.2
unnamed: C33.2, IC2.27 (UCAP)
unnamed: D1.1 (K), IC2.10 ((INT5/AIN3)PD4)
unnamed: D1.2 (A), R14.2
unnamed: D2.1 (K), IC2.11 ((XCK/AIN4/PCINT12)PD5)
unnamed: D2.2 (A), R15.2
unnamed: F1.1, P1.1 (VCC)
unnamed: IC2.9 ((TXD1/INT3)PD3), IC3.1 (~OE), IC3.2 (A)
unnamed: IC2.13 ((~CTS~/~HWB~/AIN6/T0/INT7)PD7), R10.2
unnamed: IC2.22 ((INT4/ICP1/CLK0)PC7), R12.2
unnamed: IC2.23 ((OC.1A/PCINT8)PC6), Q2.1 (G), R16.2
unnamed: IC2.26 ((PCINT10)PC4), R11.2

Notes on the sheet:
Program
Native
* Not mounted

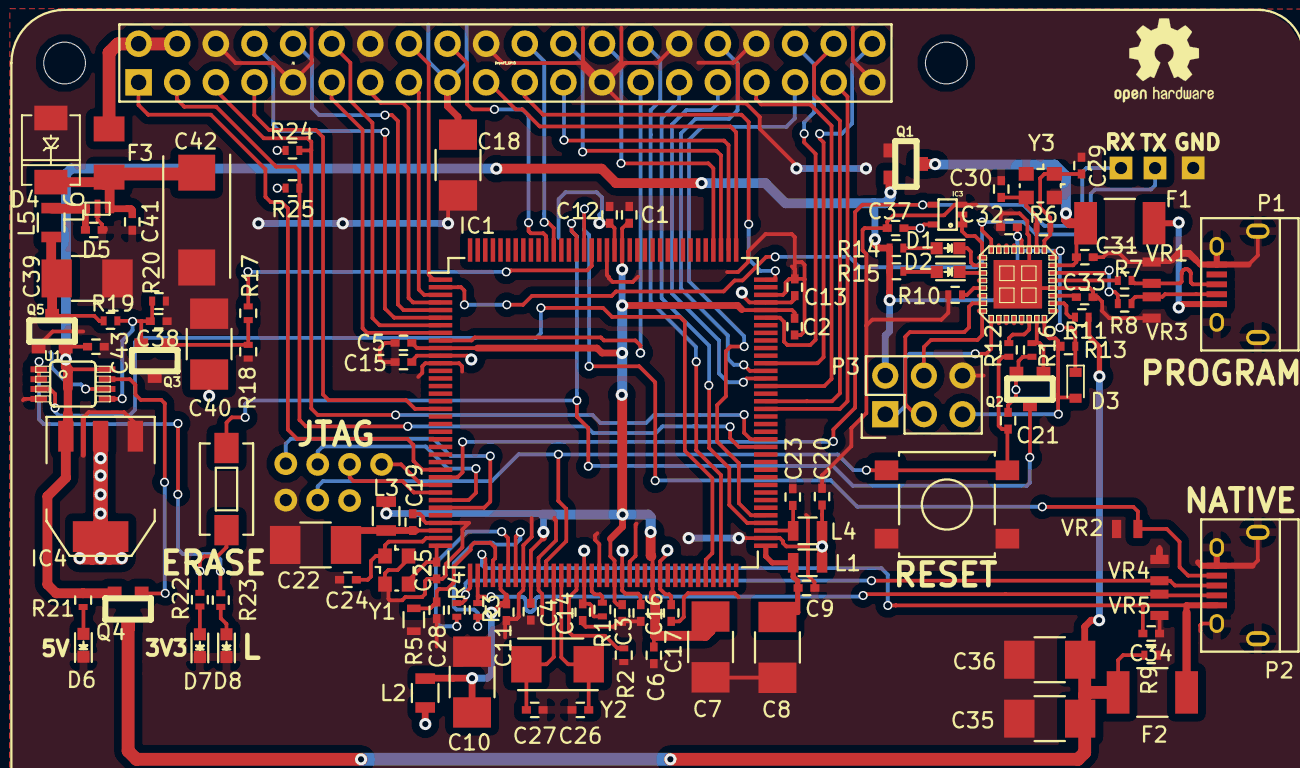
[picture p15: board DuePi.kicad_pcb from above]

Board: 2 copper layers, 120 parts (0 on the bottom side), 94 nets.

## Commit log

2017-02-08 Create Gerber
2017-02-08 Files Gerber for DuePi
2017-02-09 Mapping Pin Arduino Due- DuePi
2017-04-18 PCB Image V1.0.1
